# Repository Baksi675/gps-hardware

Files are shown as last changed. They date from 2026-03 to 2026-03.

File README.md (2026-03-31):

# GPS Tracking Device — Hardware

An electronic device built for GPS tracking. The project was made with KiCad.

For the firmware repository visit gps-firmware: https://github.com/Baksi675/gps-firmware

---

## Features

- STM32F401RE microcontroller.
- 32.768 kHz crystal oscillator for the internal RTC of the microcontroller.
- USB micro B connector to power the board and to provide USB based host - target runtime communication.
- USBLC6-2SC6 ESD protection diode network to protect the USB connector from ESD events.
- CH340C USB-UART converter IC to provide communication capabilities between host and target with a USB cable.
- LD30950PU33R LDO for 5 V to 3.3 V conversion.
- u-blox NEO-6M GPS module connected to the microcontroller via UART.
- U.FL antenna connector for the ceramic patch antenna.
- 3 V CR2032 coin cell for the internal RTC of the microcontroller.
- microSD card slot connected to the microcontroller via SPI.
- Three user button connectors.
- A 4 pin connector for the display (I2C).
- A 5 pin debug connector (SWD).
- A connector for an external GPS module in case the on-board module is not operational (UART).

---

## Demonstration playlist

https://www.youtube.com/watch?v=A6QJqgy0O1o&list=PLb_bXLsinHOQtkZ2X2QlIw-E_5eapHqGd

---

GPS board

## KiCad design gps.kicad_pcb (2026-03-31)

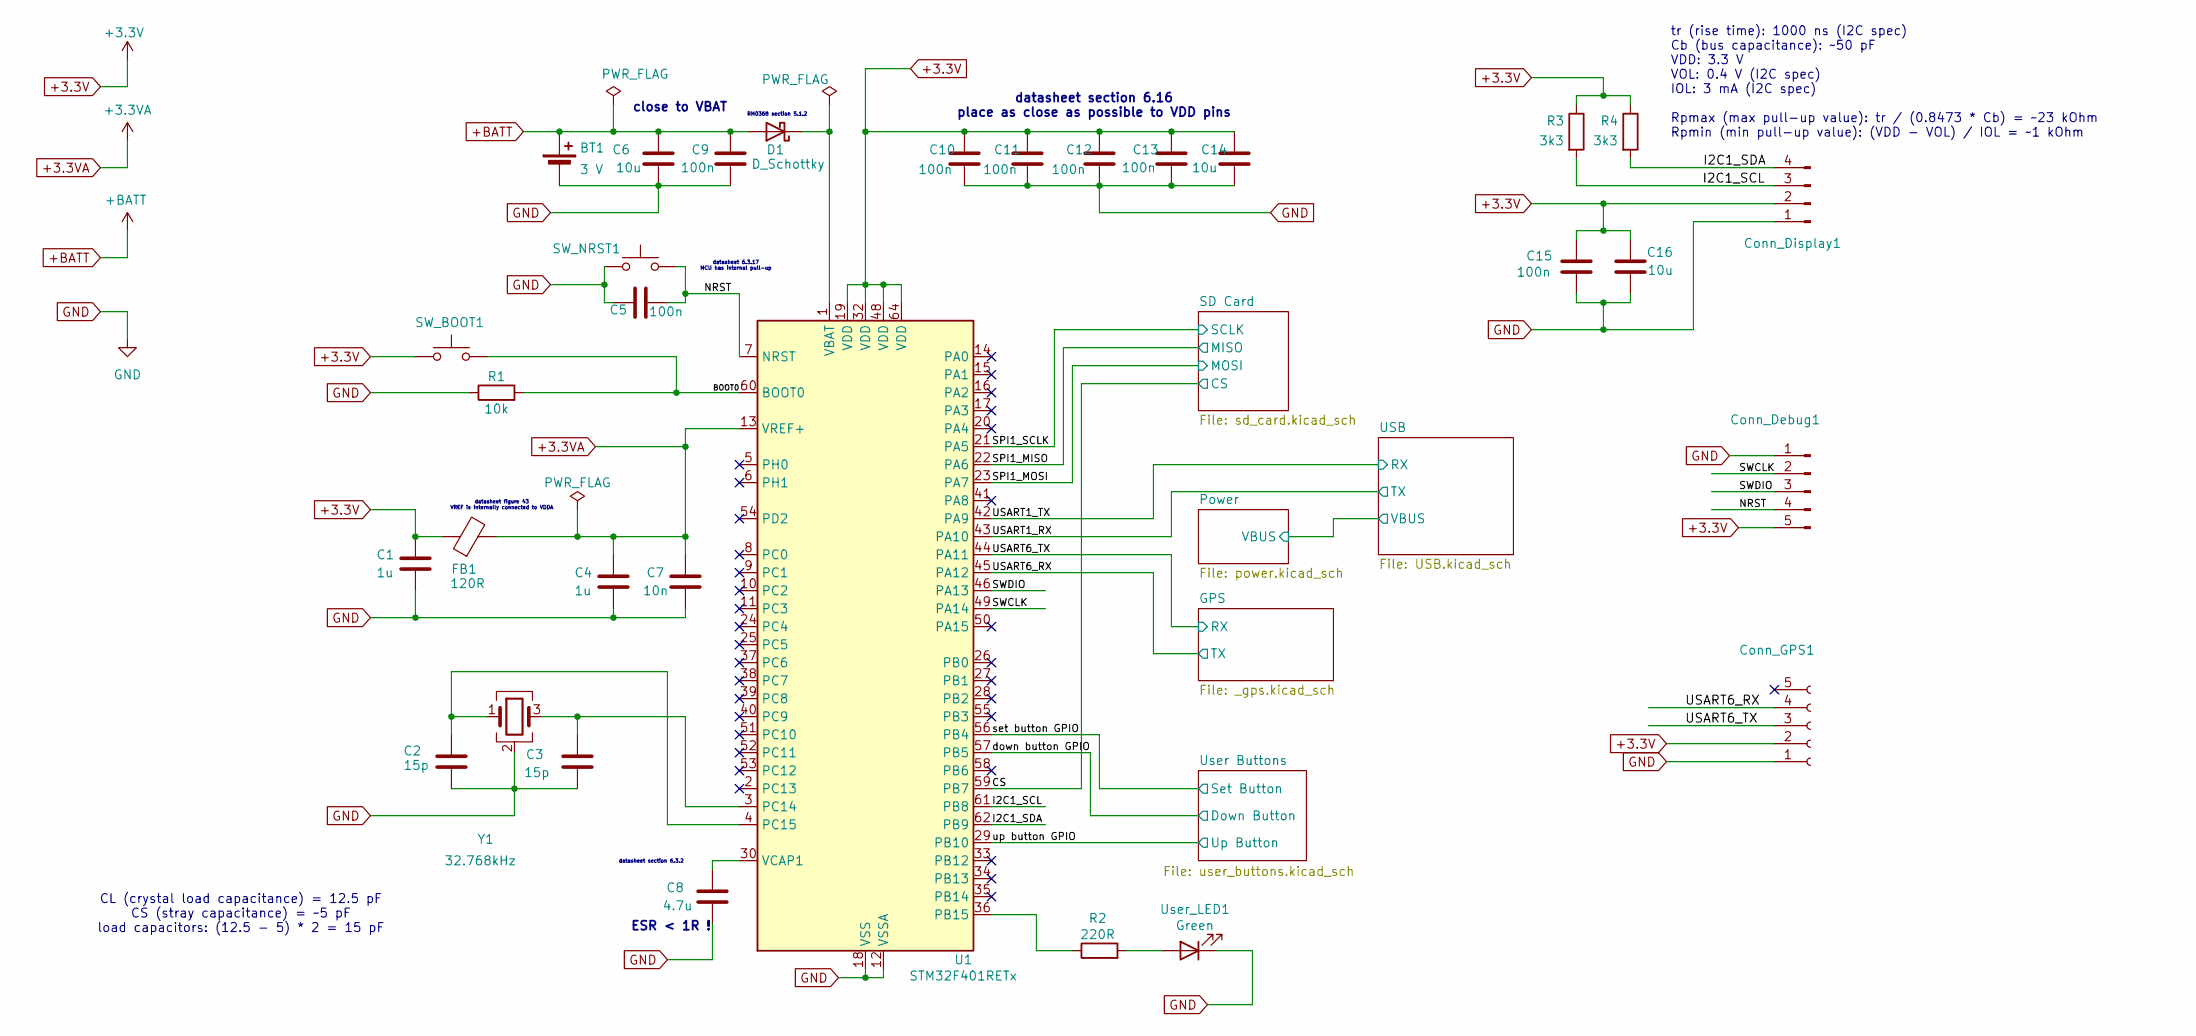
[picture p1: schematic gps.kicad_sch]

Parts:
BT1: 3 V; BatteryHolder_MYOUNG_BS-07-A1BJ001_CR2032
C1, C4: 1u; C_0603_1608Metric
C2, C3: 15p; C_0603_1608Metric
C5, C9, C10, C11, C12, C13, C15: 100n; C_0402_1005Metric
C6, C14, C16: 10u; C_0603_1608Metric
C7: 10n; C_0402_1005Metric
C8: 4.7u; C_0603_1608Metric
Conn_Debug1: Conn_01x05_Pin; PinHeader_1x05_P2.54mm_Vertical
Conn_Display1: Conn_01x04_Pin; PinHeader_1x04_P2.54mm_Vertical
Conn_GPS1: Conn_01x05_Socket; PinSocket_1x05_P2.54mm_Vertical
D1: D_Schottky; D_0603_1608Metric
FB1: 120R; L_0603_1608Metric
R1: 10k; R_0402_1005Metric
R2: 220R; R_0402_1005Metric
R3, R4: 3k3; R_0402_1005Metric
SW_BOOT1: SW_Push; SW_Push_1P1T_NO_E-Switch_TL3301NxxxxxG
SW_NRST1: SW_Push; SW_Push_1P1T_NO_E-Switch_TL3301NxxxxxG
U1: STM32F401RETx; LQFP-64_10x10mm_P0.5mm
User_LED1: Green; LED_0603_1608Metric
Y1: 32.768kHz; Crystal_SMD_SeikoEpson_MC306-4Pin_8.0x3.2mm

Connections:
+3.3V: C1.1, C10.1, C11.1, C12.1, C13.1, C14.1, C15.2, C16.2, Conn_Debug1.5, Conn_Display1.2, Conn_GPS1.2, FB1.1, R3.1, R4.1, SW_BOOT1.1, U1.19 (VDD), U1.32 (VDD), U1.48 (VDD), U1.64 (VDD); also elsewhere on the board
+3.3VA: C4.1, C7.1, FB1.2, U1.13 (VREF+)
+BATT: BT1.1 (+), C6.1, C9.1, D1.2 (A); also elsewhere on the board
/BOOT0: R1.2, SW_BOOT1.2, U1.60 (BOOT0)
/CS: U1.59 (PB7); also elsewhere on the board
/I2C1_SCL: Conn_Display1.3, R3.2, U1.61 (PB8)
/I2C1_SDA: Conn_Display1.4, R4.2, U1.62 (PB9)
/NRST: C5.2, Conn_Debug1.4, SW_NRST1.2, U1.7 (NRST)
/SPI1_MISO: U1.22 (PA6); also elsewhere on the board
/SPI1_MOSI: U1.23 (PA7); also elsewhere on the board
/SPI1_SCLK: U1.21 (PA5); also elsewhere on the board
/SWCLK: Conn_Debug1.2, U1.49 (PA14)
/SWDIO: Conn_Debug1.3, U1.46 (PA13)
/USART1_RX: U1.43 (PA10); also elsewhere on the board
/USART1_TX: U1.42 (PA9); also elsewhere on the board
/USART6_RX: Conn_GPS1.4, U1.45 (PA12); also elsewhere on the board
/USART6_TX: Conn_GPS1.3, U1.44 (PA11); also elsewhere on the board
/down button GPIO: U1.57 (PB5); also elsewhere on the board
/set button GPIO: U1.56 (PB4); also elsewhere on the board
/up button GPIO: U1.29 (PB10); also elsewhere on the board
GND: BT1.2 (-), C1.2, C2.2, C3.2, C4.2, C5.1, C6.2, C7.2, C8.2, C9.2, C10.2, C11.2, C12.2, C13.2, C14.2, C15.1, C16.1, Conn_Debug1.1, Conn_Display1.1, Conn_GPS1.1, R1.1, SW_NRST1.1, U1.12 (VSSA), U1.18 (VSS), U1.31 (VSS), U1.47 (VSS), U1.63 (VSS), User_LED1.1 (K), Y1.2 (G), Y1.4 (G); also elsewhere on the board
unnamed: D1.1 (K), U1.1 (VBAT)
unnamed: R2.1, U1.36 (PB15)
unnamed: C3.1, U1.3 (PC14), Y1.3
unnamed: C2.1, U1.4 (PC15), Y1.1
unnamed: C8.1, U1.30 (VCAP1)
unnamed: R2.2, User_LED1.2 (A)

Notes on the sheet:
CL (crystal load capacitance) = 12.5 pF CS (stray capacitance) = ~5 pF load capacitors: (12.5 - 5) * 2 = 15 pF
close to VBAT
datasheet figure 43 VREF is internally connected to VDDA
ESR < 1R !
datasheet section 6.3.2
datasheet section 6.16 place as close as possible to VDD pins
tr (rise time): 1000 ns (I2C spec) Cb (bus capacitance): ~50 pF VDD: 3.3 V VOL: 0.4 V (I2C spec) IOL: 3 mA (I2C spec) Rpmax (max pull-up value): tr / (0.8473 * Cb) = ~23 kOhm Rpmin (min pull-up value): (VDD - VOL) / IOL = ~1 kOhm
RM0368 section 5.1.2
datasheet 6.3.17 MCU has internal pull-up

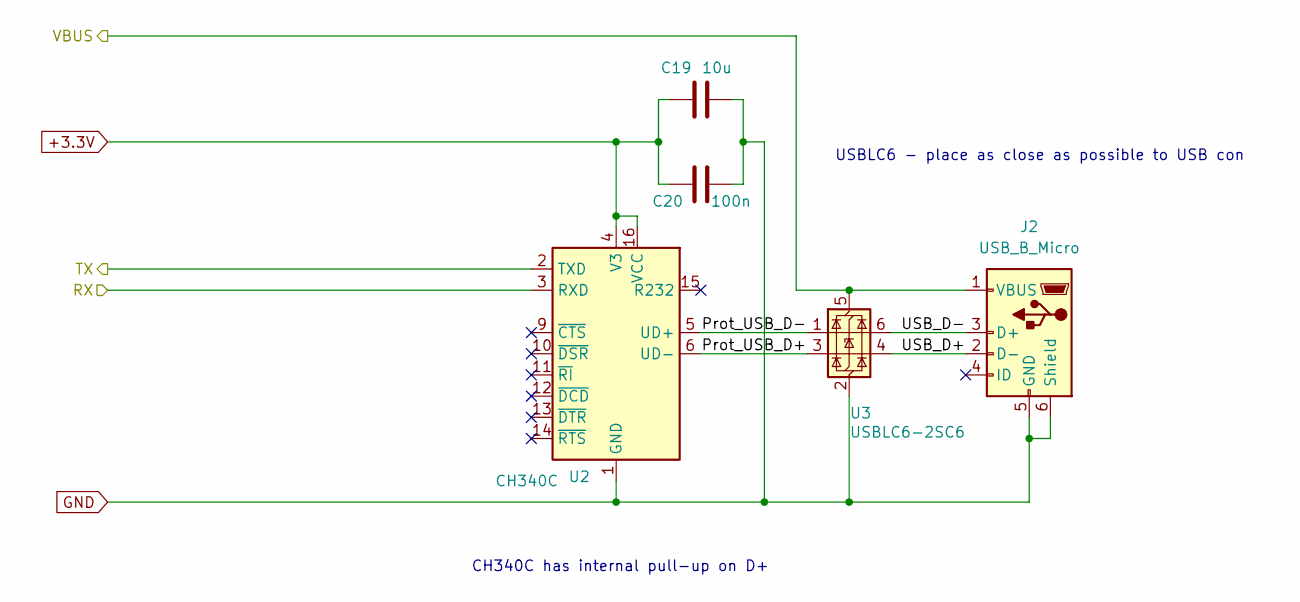
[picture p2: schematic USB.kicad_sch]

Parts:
C19: 10u; C_0603_1608Metric
C20: 100n; C_0402_1005Metric
J2: USB_B_Micro; USB_Micro-B_Amphenol_10118194-0001LF_Horizontal
U2: CH340C; SOIC-16_3.9x9.9mm_P1.27mm
U3: USBLC6-2SC6; SOT-23-6

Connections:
+3.3V: C19.1, C20.1, U2.4 (V3), U2.16 (VCC); also elsewhere on the board
/Power/VBUS: J2.1 (VBUS), U3.5 (VBUS); also elsewhere on the board
/USART1_RX: U2.2 (TXD); also elsewhere on the board
/USART1_TX: U2.3 (RXD); also elsewhere on the board
/USB/Prot_USB_D+: U2.6 (UD-), U3.3 (I/O2)
/USB/Prot_USB_D-: U2.5 (UD+), U3.1 (I/O1)
/USB/USB_D+: J2.2 (D-), U3.4 (I/O2)
/USB/USB_D-: J2.3 (D+), U3.6 (I/O1)
GND: C19.2, C20.2, J2.5 (GND), J2.6 (Shield), U2.1 (GND), U3.2 (GND); also elsewhere on the board

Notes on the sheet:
CH340C has internal pull-up on D+
USBLC6 - place as close as possible to USB con

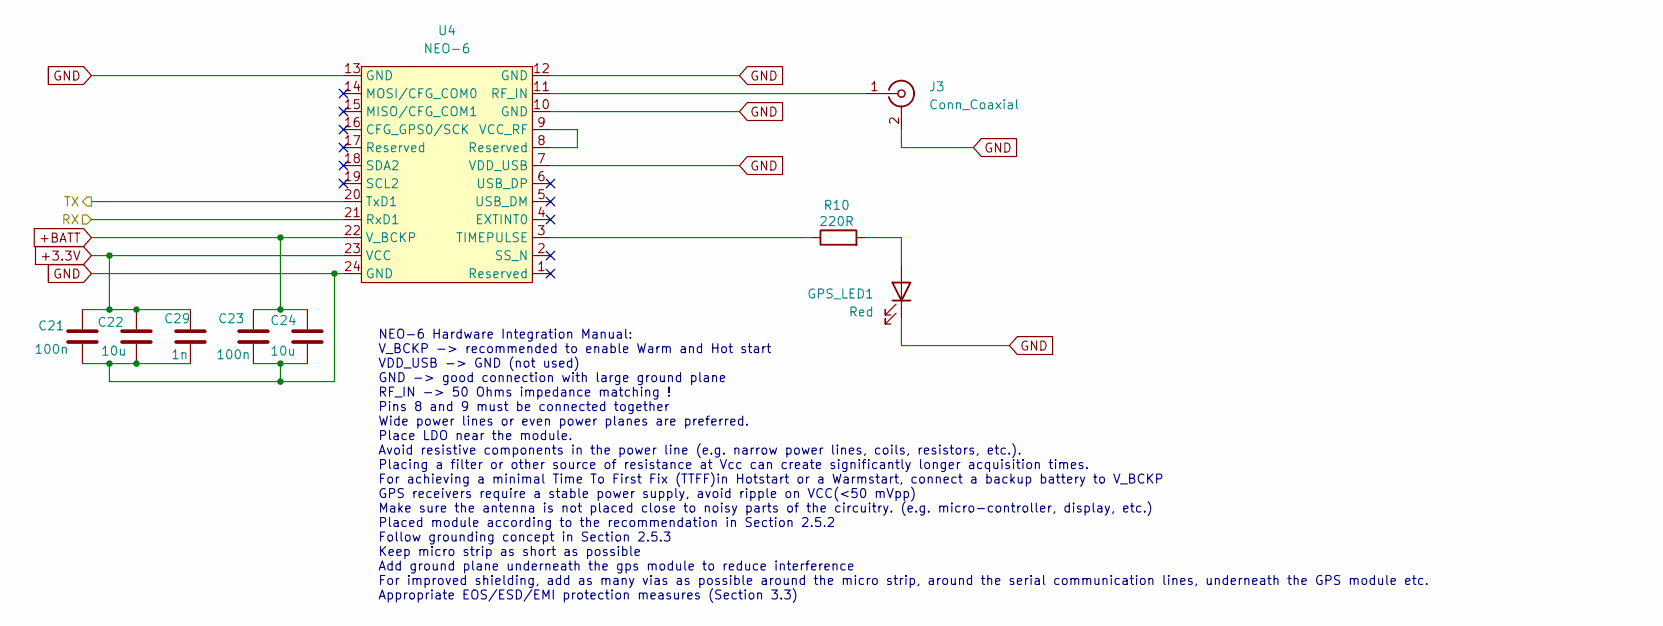
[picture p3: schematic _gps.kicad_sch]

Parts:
C21, C23: 100n; C_0402_1005Metric
C22, C24: 10u; C_0603_1608Metric
C29: 1n; C_0402_1005Metric
GPS_LED1: Red; LED_0603_1608Metric
J3: Conn_Coaxial; U.FL_Hirose_U.FL-R-SMT-1_Vertical
R10: 220R; R_0402_1005Metric
U4: NEO-6; ublox_NEO

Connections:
+3.3V: C21.1, C22.1, C29.1, U4.23 (VCC); also elsewhere on the board
+BATT: C23.1, C24.1, U4.22 (V_BCKP); also elsewhere on the board
/USART6_RX: U4.20 (TxD1); also elsewhere on the board
/USART6_TX: U4.21 (RxD1); also elsewhere on the board
GND: C21.2, C22.2, C23.2, C24.2, C29.2, GPS_LED1.1 (K), J3.2 (Ext), U4.7 (VDD_USB), U4.10 (GND), U4.12 (GND), U4.13 (GND), U4.24 (GND); also elsewhere on the board
unnamed: GPS_LED1.2 (A), R10.2
unnamed: J3.1 (In), U4.11 (RF_IN)
unnamed: R10.1, U4.3 (TIMEPULSE)
unnamed: U4.8 (Reserved), U4.9 (VCC_RF)

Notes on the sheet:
NEO-6 Hardware Integration Manual: V_BCKP -> recommended to enable Warm and Hot start VDD_USB -> GND (not used) GND -> good connection with large ground plane RF_IN -> 50 Ohms impedance matching ! Pins 8 and 9 must be connected together Wide power lines or even power planes are preferred. Place LDO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

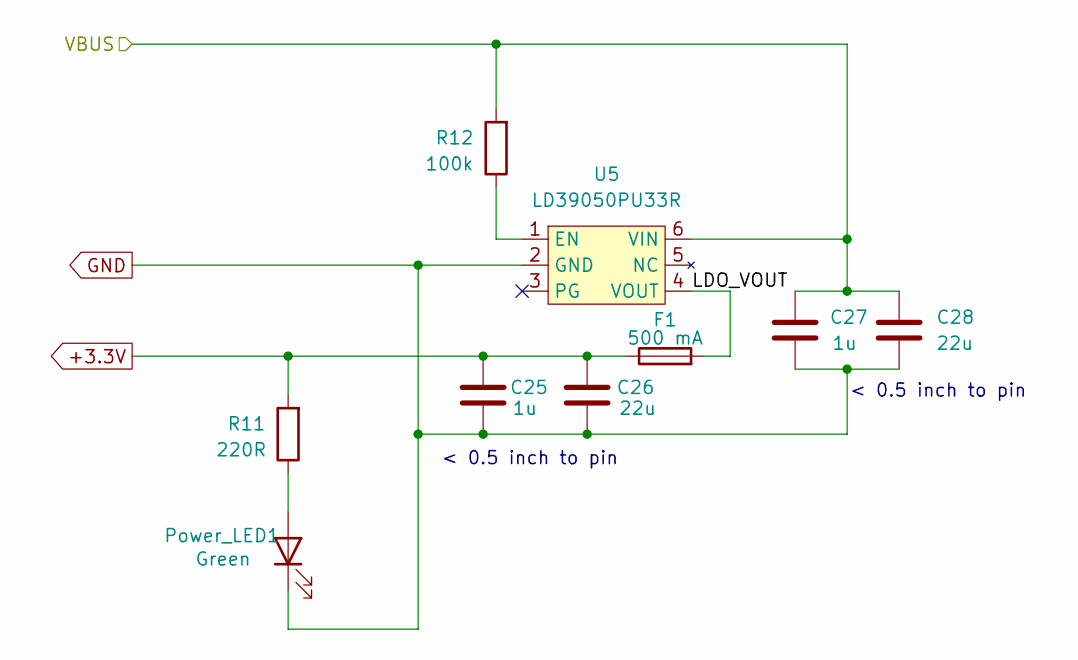
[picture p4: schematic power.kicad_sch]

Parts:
C25, C27: 1u; C_0603_1608Metric
C26, C28: 22u; C_0805_2012Metric
F1: 500 mA; Fuse_0603_1608Metric
Power_LED1: Green; LED_0603_1608Metric
R11: 220R; R_0402_1005Metric
R12: 100k; R_0402_1005Metric
U5: LD39050PU33R

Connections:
+3.3V: C25.1, C26.1, F1.1, R11.2; also elsewhere on the board
/Power/LDO_VOUT: F1.2, U5.4 (VOUT)
/Power/VBUS: C27.1, C28.1, R12.2, U5.6 (VIN); also elsewhere on the board
GND: C25.2, C26.2, C27.2, C28.2, Power_LED1.1 (K), U5.2 (GND); also elsewhere on the board
unnamed: Power_LED1.2 (A), R11.1
unnamed: R12.1, U5.1 (EN)

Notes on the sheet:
< 0.5 inch to pin

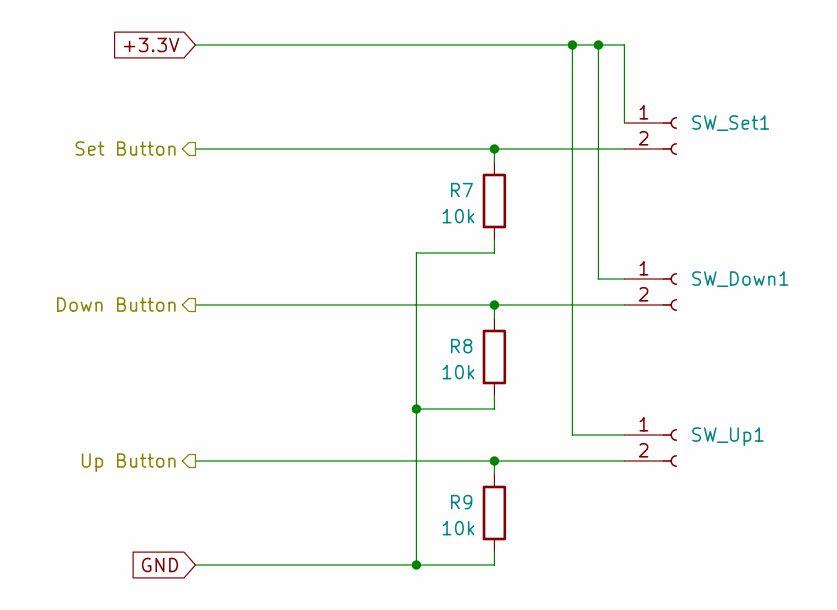
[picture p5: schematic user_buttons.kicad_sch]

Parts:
R7, R8, R9: 10k; R_0402_1005Metric
SW_Down1: Conn_01x02_Socket; PinSocket_1x02_P2.54mm_Vertical
SW_Set1: Conn_01x02_Socket; PinSocket_1x02_P2.54mm_Vertical
SW_Up1: Conn_01x02_Socket; PinSocket_1x02_P2.54mm_Vertical

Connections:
+3.3V: SW_Down1.1, SW_Set1.1, SW_Up1.1; also elsewhere on the board
/down button GPIO: R8.1, SW_Down1.2; also elsewhere on the board
/set button GPIO: R7.1, SW_Set1.2; also elsewhere on the board
/up button GPIO: R9.1, SW_Up1.2; also elsewhere on the board
GND: R7.2, R8.2, R9.2; also elsewhere on the board

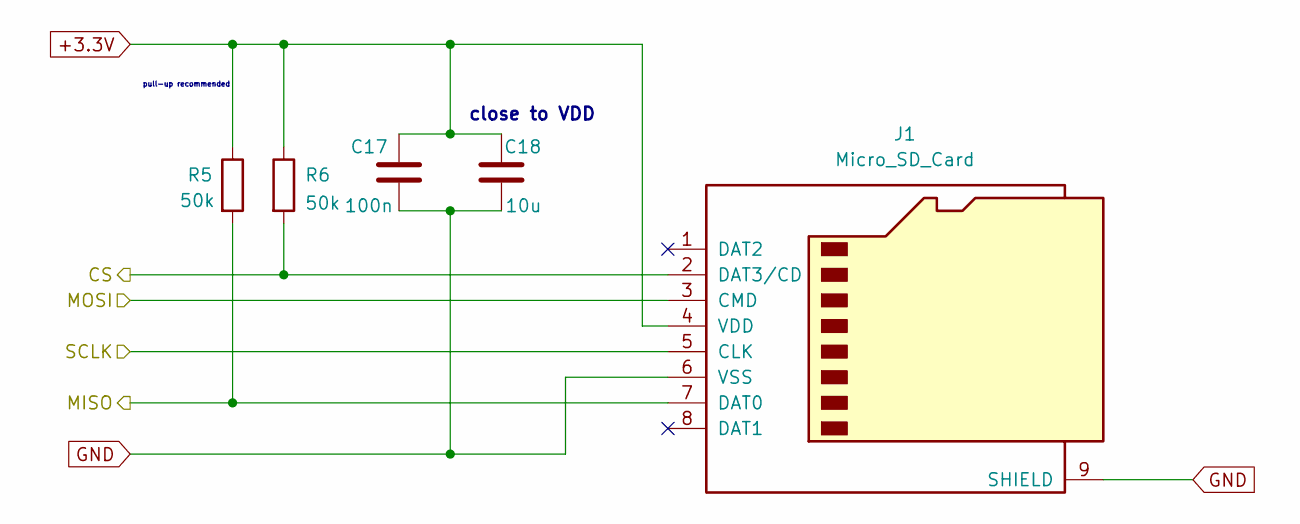
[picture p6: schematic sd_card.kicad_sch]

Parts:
C17: 100n; C_0402_1005Metric
C18: 10u; C_0603_1608Metric
J1: Micro_SD_Card; microSD_HC_Molex_104031-0811
R5, R6: 50k; R_0402_1005Metric

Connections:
+3.3V: C17.2, C18.2, J1.4 (VDD), R5.1, R6.1; also elsewhere on the board
/CS: J1.2 (DAT3/CD), R6.2; also elsewhere on the board
/SPI1_MISO: J1.7 (DAT0), R5.2; also elsewhere on the board
/SPI1_MOSI: J1.3 (CMD); also elsewhere on the board
/SPI1_SCLK: J1.5 (CLK); also elsewhere on the board
GND: C17.1, C18.1, J1.6 (VSS), J1.9 (SHIELD); also elsewhere on the board

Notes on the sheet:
pull-up recommended
close to VDD

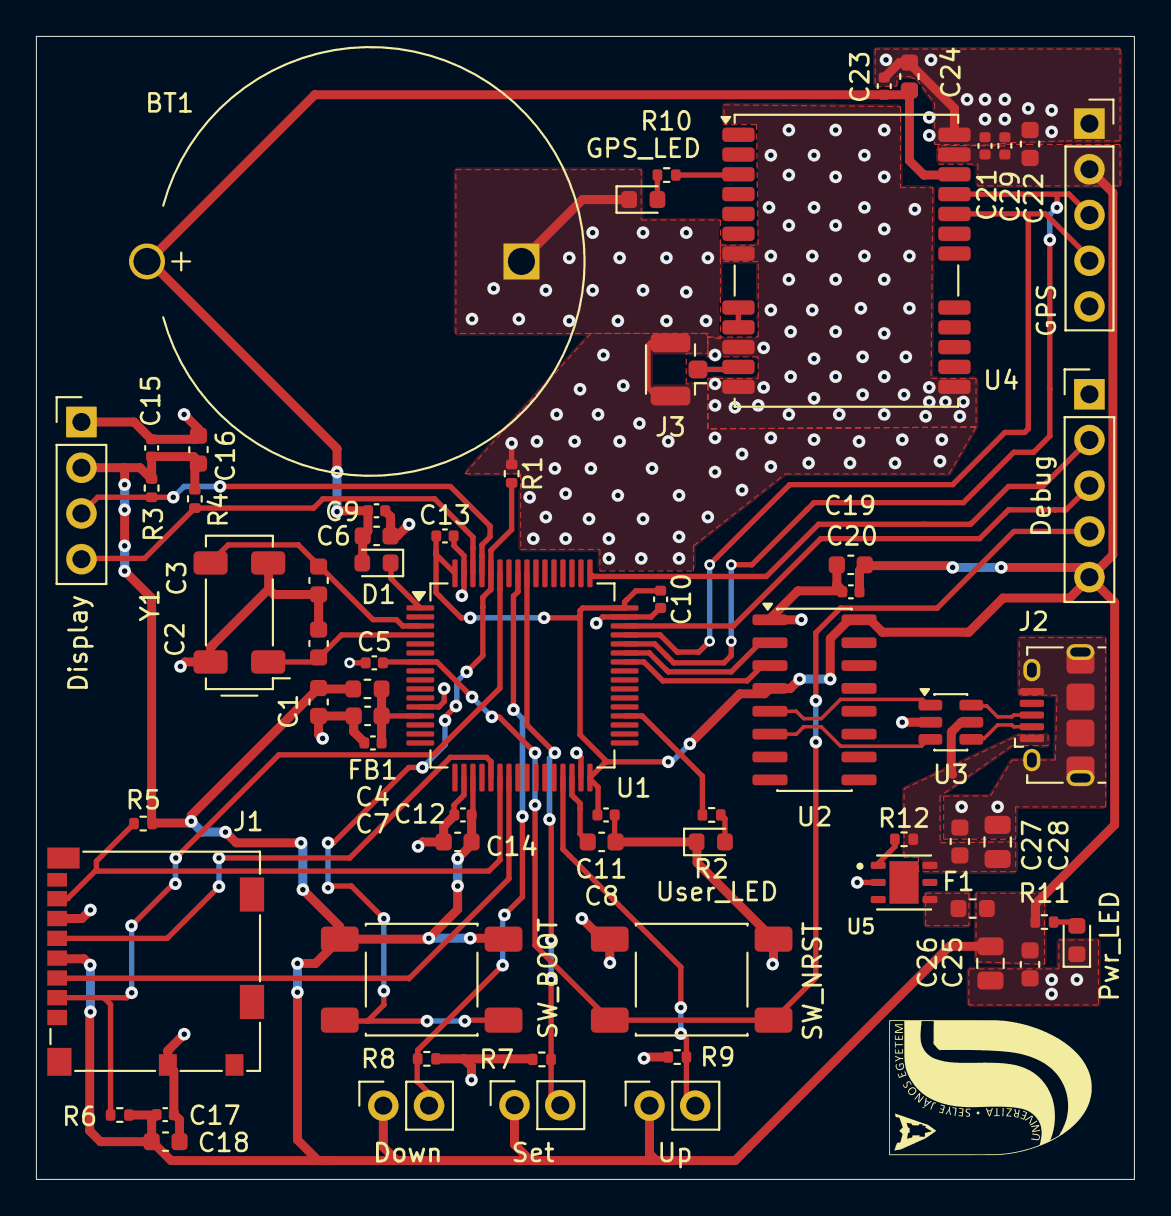
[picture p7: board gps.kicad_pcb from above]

Board: 2 copper layers, 61.0 x 63.5 mm, 65 parts (0 on the bottom side), 39 nets.
